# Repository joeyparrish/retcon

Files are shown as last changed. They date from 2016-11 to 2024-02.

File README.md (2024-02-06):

RetCon

# Retro Console Controller

Use comfortable wireless PS3 controllers on your old Sega or Nintendo system.

> :warning: **NOTE** :warning:: _**This project has been deprecated.**_
> 
> I bought receivers from 8bitdo that do much more than my homebrew project ever could, in a smaller space, for less money.
> For example, here you can get a Sega Genesis receiver for bluetooth controllers that is tiny and powered by the Sega itself: https://www.8bitdo.com/retro-receiver-genesis-mega-drive/
> 
> I had begun a redesign based on a microcontroller that I hoped would be powered by the console itself, and would use generic Bluetooth instead of PS3, but for $20 (as of Feb 2024) it's hard to beat what 8bitdo is doing.
> 
> Feel free to build off of this repo if you wish, but I'm abandoning it in favor of https://www.8bitdo.com/
> 
> -Joey

-----

The PS3 controllers pair with a Raspberry Pi, which translates the controller
inputs to the game console through an external circuit.

[The repository][] hosts the schematics, board layouts, and source code.

For a list of known issues, see our [issue tracker][].

[The repository]: https://github.com/cashpipeplusplus/retcon
[issue tracker]: https://github.com/cashpipeplusplus/retcon/issues

## Software

RetCon consists of three pieces of software that run on a Raspberry Pi:

 * retcon - reads events from the gamepad and toggle GPIO pins
 * trusting-steed - waits for gamepads and marks them as "trusted"
 * sixpair - waits for PS3 controllers over USB and pairs them for bluetooth

These run on the Raspberry Pi, and I do not recommend cross-compiling them.
To build them, check out the source on Raspbian, install the deps, then build
the debian package:

```sh
git clone https://github.com/cashpipeplusplus/retcon
sudo apt-get install libusb-dev pigpio python-gobject python-dbus
cd retcon/src/
fakeroot ./debian/rules binary
```

To install on Raspbian:

```sh
sudo dpkg -i ../retcon_0.0.1-1_armhf.deb
```

## Raspberry Pi SD card image

The SD card image is generated using a fork of a tool called pi-gen, which is
included as a submodule.

From retcon, you can check out the pi-gen code like this:

```sh
git submodule update --init --recursive
```

To build the SD image, first you must build the retcon debian package from
Raspbian.  Then, copy the deb file to your Linux machine and build the SD image
there.  Assuming the deb file is in the retcon folder, run this:

```sh
cd pi-gen
sudo ./build.sh ../retcon_0.0.1-1_armhf.deb
```

The output will appear in `deploy/`.

## Pre-built SD card image

Pre-built SD card images are available from the [releases][] page.

[releases]: https://github.com/cashpipeplusplus/retcon/releases

## Hardware

The Raspberry Pi communicates with the game console through an external
circuit.  Schematics and board layouts for this extra hardware can be found
in the `circuit/` folder.  The board file can be uploaded directly to
[DirtyPCBs][] if you want the boards printed for you.  More details can be
found in `circuit/README.md`.

[DirtyPCBs]: http://dirtypcbs.com/

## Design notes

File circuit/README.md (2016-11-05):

These are the schematic and board files for the external circuit part of the
project.  This circuit is driven by the Raspberry Pi and translates GPIO pins
to the game console.

These files were created with the free version of [Eagle][] v7.7.0.

 - sega.sch (Eagle Schematic)
 - sega.sch.1.png (screenshot of the schematic)
 - sega.sch.2.png (screenshot of the schematic)
 - sega.brd (Eagle Board)
 - sega.brd.png (screenshot of the board)

The board file can be uploaded directly to [DirtyPCBs][] to be printed.

[Eagle]: https://cadsoft.io/
[DirtyPCBs]: http://dirtypcbs.com/

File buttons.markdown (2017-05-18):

## Button Mappings

|PS3 |Master System |Genesis |NES |SNES |Output |
|---|---|---|---|---|---|
|D-pad |D-pad |D-pad |D-pad  |D-pad  |U, D, L, R|
|L stick |D-pad |D-pad |D-pad  |D-pad  |U, D, L, R|
|R stick |- |- |- |- |- |
|select |- |- |select |select |SL |
|start |- |start |start  |start  |ST |
|PS button |- |- |- |- |- |
|square |- |A |B |Y |A |
|X |button 1 |B |A |B |B |
|circle |button 2 |C |- |A |C |
|triangle  |- |- |- |X |X |
|L1 |- |- |- |TL |TL |
|R1 |- |- |- |TR |TR |
|L2 |- |- |- |- |- |
|R2 |- |C¹ |- |A |C¹ |
|L3 |- |- |- |- |- |
|R3 |- |- |- |- |- |

¹: Alternate binding for C on Genesis, for convenience

## Pin Mappings

|Output name |P1 connector pin² |P2 connector pin² |P1 BCM pin³ |P2 BCM pin³ |
|---|---|---|---|---|
|U | 8 |21 |14 | 9 |
|D |18 |11 |24 |17 |
|L |16 |13 |23 |27 |
|R |12 |15 |18 |22 |
|SL |38 |23 |20 |11 |
|ST |10 |19 |15 |10 |
|A |26 | 3 | 7 | 2 |
|B |24 | 5 | 8 | 3 |
|C |22 | 7 |25 | 4 |
|X |36 |27 |16 | 0 |
|TL |32 |29 |12 | 5 |
|TR |28 |31 | 1 | 6 |

²: Pins on the Raspberry Pi's GPIO connector

³: Pins on the Raspberry Pi's Broadcom CPU

See also: https://pinout.xyz/

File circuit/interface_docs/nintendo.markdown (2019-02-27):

# Nintendo Entertainment System and Super Nintendo Controller Interface

## Connectors

Sega made it so easy with DB9.  Nintendo's connectors are not only non-standard,
they changed the connector from the NES to the SNES.  The socket on the game
console is male, and the plug on the end of the controllers is female.

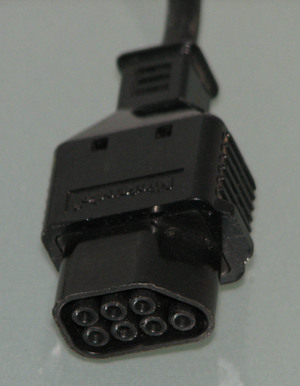
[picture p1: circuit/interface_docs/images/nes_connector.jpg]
female NES plug

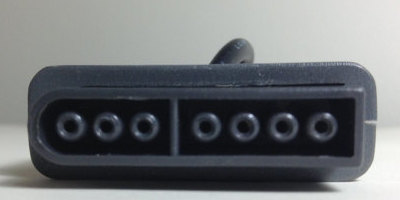
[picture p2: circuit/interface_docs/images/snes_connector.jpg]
female SNES plug


## Controller interfaces

The NES controller has a D-pad and buttons A, B, start, and select.
The SNES controller adds X, Y, and L & R shoulder buttons to the NES layout.
The controller interface is a 5V serial interface with active-low signals.
Pins are pulled high in the controller and pushing a button connects the pin
to ground.

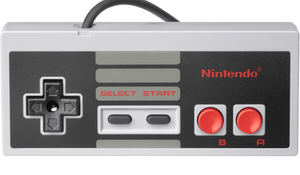
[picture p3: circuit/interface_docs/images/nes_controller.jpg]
NES controller

NES connector pins
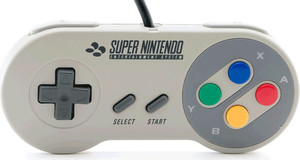
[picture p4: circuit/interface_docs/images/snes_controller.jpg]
SNES controller

SNES connector pins

The serial interface works by latching all of the button states into a shift
register, then clocking out each individual button state.  The button states
form an 8-bit (NES) or 16-bit (SNES) word.

|pin|signal |NES color¹|SNES color¹|
|---|---|---|---|
|1  |Ground (from console)|white |black |
|2  |(not used) | | |
|3  |(not used) | | |
|4  |Serial output |black |red |
|5  |Latch (from console) |green |yellow |
|6  |Clock (from console) |yellow |blue |
|7  |+5V (from console) |red |green |

¹: In the extension cords I bought... YMMV

|bit|NES button|SNES button|
|---|---|---|
|0  |A |B |
|1  |B |Y |
|2  |Select |Select |
|3  |Start |Start |
|4  |Up |Up |
|5  |Down |Down |
|6  |Left |Left |
|7  |Right |Right |
|8  |(not used)|A |
|9  |(not used)|X |
|10 |(not used)|L |
|11 |(not used)|R |
|12 |(not used)|(not used) |
|13 |(not used)|(not used) |
|14 |(not used)|(not used) |
|15 |(not used)|(not used) |

Any extra bits in the shift register's parallel input must be pulled high.

### External References

 - http://gamesx.com/wiki/doku.php?id=controls:nes_snes_controller
 - http://pinoutguide.com/Game/snescontroller_pinout.shtml

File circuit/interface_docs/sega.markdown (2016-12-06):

# Sega Genesis and Master System Controller Interface

## Connector

The connector is a slight variation on a normal DB9 connector.  The socket on
the game console is male, and the plug on the end of the controller is female.

A normal DB9 female plug won't fit into the Sega controller port.  The socket
on the game console is a little too deep, and the metal shielding on the female
plug makes the whole thing too wide.

It seems that the best way to connect our circuit to the Sega is via an
extension cable that is meant for Sega Genesis.

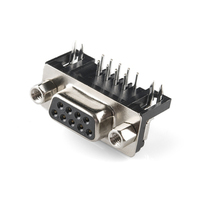
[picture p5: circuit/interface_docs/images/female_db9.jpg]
female DB9 plug

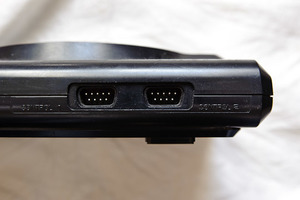
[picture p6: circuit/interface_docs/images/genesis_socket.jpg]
Sega Genesis controller socket

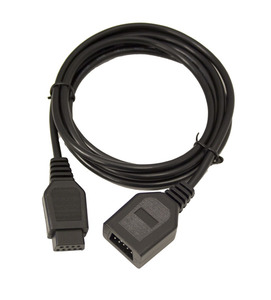
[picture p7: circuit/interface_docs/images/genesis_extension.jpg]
Sega Genesis extension cable


## Sega Master System Controller

The Master System controller has a D-pad and two buttons.  The controller
interface is a 5V parallel interface with active-low signals.  Pins are
pulled high in the controller and pushing a button connects the pin to ground.

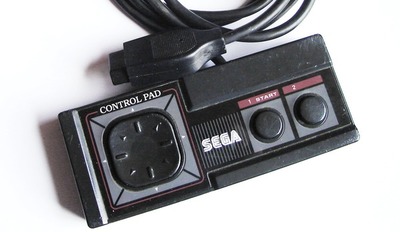
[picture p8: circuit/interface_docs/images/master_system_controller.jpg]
Sega Master System Controller

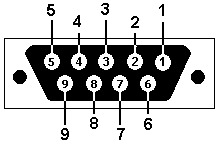
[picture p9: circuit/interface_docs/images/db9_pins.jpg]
DB9 connector pins


|pin|signal |
|---|---|
|1  |Up |
|2  |Down |
|3  |Left |
|4  |Right |
|5  |+5V (from console) |
|6  |Button 1 |
|7  |(not used) |
|8  |Ground (from console)|
|9  |Button 2 |

## Sega Genesis Controller

The Genesis controller has a D-pad, a start button, and buttons A, B, and C.
The controller interface is backward-compatible with the Sega Master System,
so a Genesis controller should work on a Master System.

To add more buttons while maintaining compatibility, the Sega Genesis adds a
select signal to the interface.  Based on the state of the select pin, the
controller multiplexes additional button states onto existing pins.  The select
pin is pulled high in the controller so that it is not left floating when the
controller is connected to a Master System.

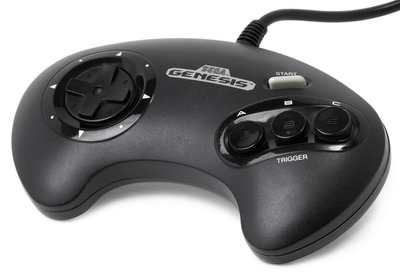
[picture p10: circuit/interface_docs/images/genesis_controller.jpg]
Sega Genesis Controller

DB9 connector pins

|pin|signal (select high) |signal (select low) |
|---|---|---|
|1  |Up |Up |
|2  |Down |Down |
|3  |Left |Ground |
|4  |Right |Ground |
|5  |+5V (from console) |+5V (from console) |
|6  |B Button |A Button |
|7  |Select (from console, +5V)|Select (from console, ground)|
|8  |Ground (from console) |Ground (from console) |
|9  |C Button |Start Button |

### External References

 - http://gamesx.com/wiki/doku.php?id=controls:megadrive_genesis_controller_3
 - http://www.haku.co.uk/pics/SegaJoypadPinout.jpg
 - https://www.cs.cmu.edu/~chuck/infopg/segasix.txt

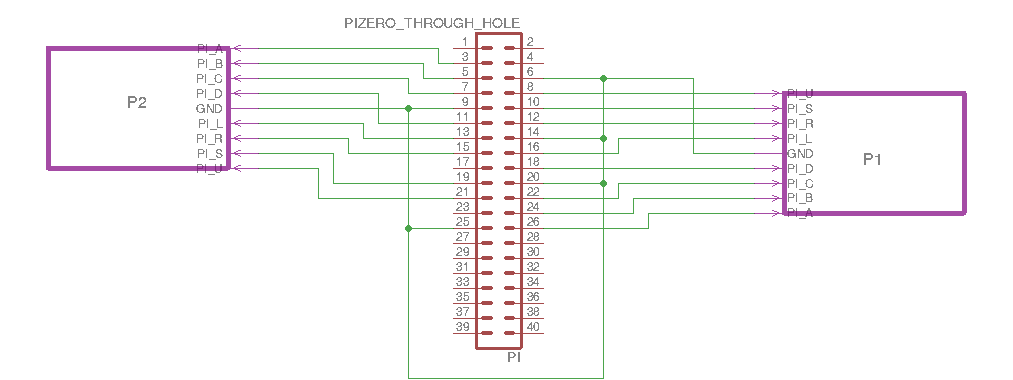
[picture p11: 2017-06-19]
circuit/sega.sch.2.png

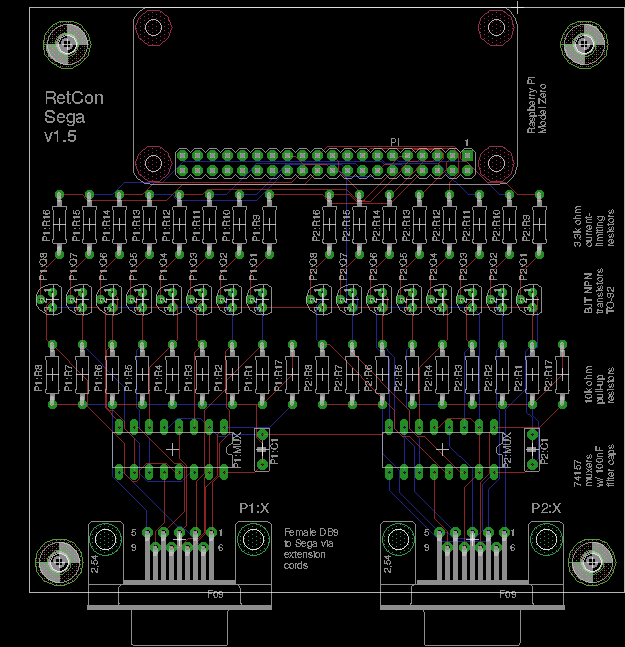
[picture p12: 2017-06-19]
circuit/sega.brd.png

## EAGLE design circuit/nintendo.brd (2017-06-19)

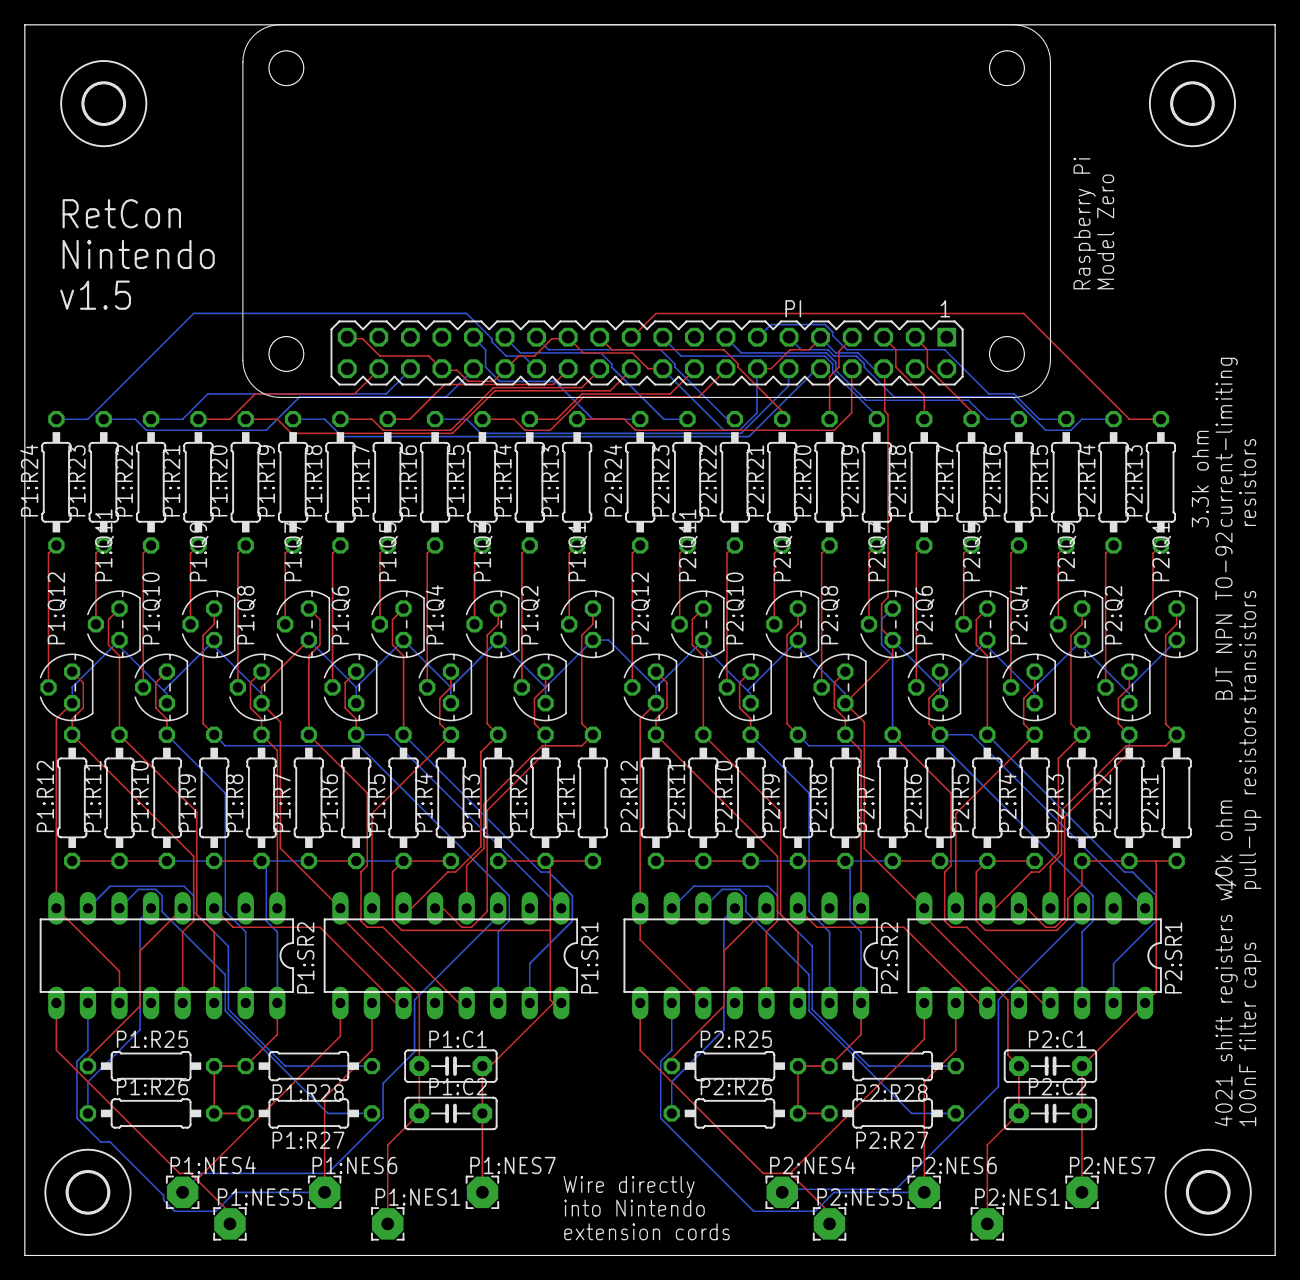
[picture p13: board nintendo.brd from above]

Board: 2 copper layers, 100.6 x 99.0 mm, 103 parts (0 on the bottom side), 91 nets.

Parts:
P1:C1, P1:C2, P2:C1, P2:C2: 100nF; C5B2.5
P1:NES1, P1:NES4, P1:NES5, P1:NES6, P1:NES7, P2:NES1, P2:NES4, P2:NES5, P2:NES6, P2:NES7: -; 2,54/1,0
P1:Q1, P1:Q2, P1:Q3, P1:Q4, P1:Q5, P1:Q6, P1:Q7, P1:Q8, P1:Q9, P1:Q10, P1:Q11, P1:Q12, P2:Q1, P2:Q2, P2:Q3, P2:Q4, P2:Q5, P2:Q6, P2:Q7, P2:Q8, P2:Q9, P2:Q10, P2:Q11, P2:Q12: 2N3904; TO92
P1:R1, P1:R2, P1:R3, P1:R4, P1:R5, P1:R6, P1:R7, P1:R8, P1:R9, P1:R10, P1:R11, P1:R12, P1:R25, P1:R26, P1:R27, P1:R28, P2:R1, P2:R2, P2:R3, P2:R4, P2:R5, P2:R6, P2:R7, P2:R8, P2:R9, P2:R10, P2:R11, P2:R12, P2:R25, P2:R26, P2:R27, P2:R28: 10k; 0207/10
P1:R13, P1:R14, P1:R15, P1:R16, P1:R17, P1:R18, P1:R19, P1:R20, P1:R21, P1:R22, P1:R23, P1:R24, P2:R13, P2:R14, P2:R15, P2:R16, P2:R17, P2:R18, P2:R19, P2:R20, P2:R21, P2:R22, P2:R23, P2:R24: 3.3k; 0207/10
P1:SR1, P1:SR2, P2:SR1, P2:SR2: 4021N; DIL16
PI: PIZERO_THROUGH_HOLE; PIZERO_THOUGH_HOLE
U$1, U$2, U$3, U$4: 3,2

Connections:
unnamed: P2:R14.2, PI.11
unnamed: P1:C1.1, P1:C2.1, P1:NES1.1, P1:Q1.3, P1:Q2.3, P1:Q3.3, P1:Q4.3, P1:Q5.3, P1:Q6.3, P1:Q7.3, P1:Q8.3, P1:Q9.3, P1:Q10.3, P1:Q11.3, P1:Q12.3, P1:SR1.8, P1:SR2.8, P1:SR2.11, P2:C1.1, P2:C2.1, P2:NES1.1, P2:Q1.3, P2:Q2.3, P2:Q3.3, P2:Q4.3, P2:Q5.3, P2:Q6.3, P2:Q7.3, P2:Q8.3, P2:Q9.3, P2:Q10.3, P2:Q11.3, P2:Q12.3, P2:SR1.8, P2:SR2.8, P2:SR2.11, PI.6, PI.9, PI.14, PI.20, PI.25, PI.30, PI.34, PI.39
unnamed: P2:R15.2, PI.13
unnamed: P2:R17.2, PI.3
unnamed: P2:R18.2, PI.5
unnamed: P2:R20.2, PI.7
unnamed: P2:R16.2, PI.15
unnamed: P2:R19.2, PI.19
unnamed: P2:R13.2, PI.21
unnamed: P1:R13.2, PI.8
unnamed: P1:R19.2, PI.10
unnamed: P1:R16.2, PI.12
unnamed: P1:R15.2, PI.16
unnamed: P1:R14.2, PI.18
unnamed: P1:R20.2, PI.22
unnamed: P1:R18.2, PI.24
unnamed: P1:R17.2, PI.26
unnamed: P2:R21.2, PI.23
unnamed: P2:R22.2, PI.27
unnamed: P2:R23.2, PI.29
unnamed: P2:R24.2, PI.31
unnamed: P1:R21.2, PI.38
unnamed: P1:R22.2, PI.36
unnamed: P1:R23.2, PI.32
unnamed: P1:R24.2, PI.28
P1:A: P1:Q5.1, P1:R5.2, P1:SR1.15
P1:B: P1:Q6.1, P1:R6.2, P1:SR1.1
P1:C: P1:Q8.1, P1:R8.2, P1:SR2.1
P1:CLK: P1:NES6.1, P1:SR1.10, P1:SR2.10
P1:D: P1:Q2.1, P1:R2.2, P1:SR1.5
P1:L: P1:Q3.1, P1:R3.2, P1:SR1.6
P1:LATCH: P1:NES5.1, P1:SR1.9, P1:SR2.9
P1:N$1: P1:Q9.2, P1:R21.1
P1:N$2: P1:Q1.2, P1:R13.1
P1:N$3: P1:Q10.2, P1:R22.1
P1:N$4: P1:Q11.2, P1:R23.1
P1:N$5: P1:Q12.2, P1:R24.1
P1:N$9: P1:Q2.2, P1:R14.1
P1:N$10: P1:Q3.2, P1:R15.1
P1:N$11: P1:Q4.2, P1:R16.1
P1:N$12: P1:Q5.2, P1:R17.1
P1:N$13: P1:Q6.2, P1:R18.1
P1:N$14: P1:Q7.2, P1:R19.1
P1:N$15: P1:Q8.2, P1:R20.1
P1:N$19: P1:SR1.11, P1:SR2.3
P1:N$20: P1:R25.1, P1:SR2.4
P1:N$21: P1:R26.1, P1:SR2.5
P1:N$22: P1:R27.1, P1:SR2.6
P1:N$23: P1:R28.1, P1:SR2.7
P1:OUT: P1:NES4.1, P1:SR1.3
P1:R: P1:Q4.1, P1:R4.2, P1:SR1.7
P1:SL: P1:Q9.1, P1:R9.2, P1:SR1.14
P1:ST: P1:Q7.1, P1:R7.2, P1:SR1.13
P1:TL: P1:Q11.1, P1:R11.2, P1:SR2.14
P1:TR: P1:Q12.1, P1:R12.2, P1:SR2.13
P1:U: P1:Q1.1, P1:R1.2, P1:SR1.4
P1:VCC: P1:C1.2, P1:C2.2, P1:NES7.1, P1:R1.1, P1:R2.1, P1:R3.1, P1:R4.1, P1:R5.1, P1:R6.1, P1:R7.1, P1:R8.1, P1:R9.1, P1:R10.1, P1:R11.1, P1:R12.1, P1:R25.2, P1:R26.2, P1:R27.2, P1:R28.2, P1:SR1.16, P1:SR2.16
P1:X: P1:Q10.1, P1:R10.2, P1:SR2.15
P2:A: P2:Q5.1, P2:R5.2, P2:SR1.15
P2:B: P2:Q6.1, P2:R6.2, P2:SR1.1
P2:C: P2:Q8.1, P2:R8.2, P2:SR2.1
P2:CLK: P2:NES6.1, P2:SR1.10, P2:SR2.10
P2:D: P2:Q2.1, P2:R2.2, P2:SR1.5
P2:L: P2:Q3.1, P2:R3.2, P2:SR1.6
P2:LATCH: P2:NES5.1, P2:SR1.9, P2:SR2.9
P2:N$1: P2:Q9.2, P2:R21.1
P2:N$2: P2:Q1.2, P2:R13.1
P2:N$3: P2:Q10.2, P2:R22.1
P2:N$4: P2:Q11.2, P2:R23.1
P2:N$5: P2:Q12.2, P2:R24.1
P2:N$9: P2:Q2.2, P2:R14.1
P2:N$10: P2:Q3.2, P2:R15.1
P2:N$11: P2:Q4.2, P2:R16.1
P2:N$12: P2:Q5.2, P2:R17.1
P2:N$13: P2:Q6.2, P2:R18.1
P2:N$14: P2:Q7.2, P2:R19.1
P2:N$15: P2:Q8.2, P2:R20.1
P2:N$19: P2:SR1.11, P2:SR2.3
P2:N$20: P2:R25.1, P2:SR2.4
P2:N$21: P2:R26.1, P2:SR2.5
P2:N$22: P2:R27.1, P2:SR2.6
P2:N$23: P2:R28.1, P2:SR2.7
P2:OUT: P2:NES4.1, P2:SR1.3
P2:R: P2:Q4.1, P2:R4.2, P2:SR1.7
P2:SL: P2:Q9.1, P2:R9.2, P2:SR1.14
P2:ST: P2:Q7.1, P2:R7.2, P2:SR1.13
P2:TL: P2:Q11.1, P2:R11.2, P2:SR2.14
P2:TR: P2:Q12.1, P2:R12.2, P2:SR2.13
P2:U: P2:Q1.1, P2:R1.2, P2:SR1.4
P2:VCC: P2:C1.2, P2:C2.2, P2:NES7.1, P2:R1.1, P2:R2.1, P2:R3.1, P2:R4.1, P2:R5.1, P2:R6.1, P2:R7.1, P2:R8.1, P2:R9.1, P2:R10.1, P2:R11.1, P2:R12.1, P2:R25.2, P2:R26.2, P2:R27.2, P2:R28.2, P2:SR1.16, P2:SR2.16
P2:X: P2:Q10.1, P2:R10.2, P2:SR2.15

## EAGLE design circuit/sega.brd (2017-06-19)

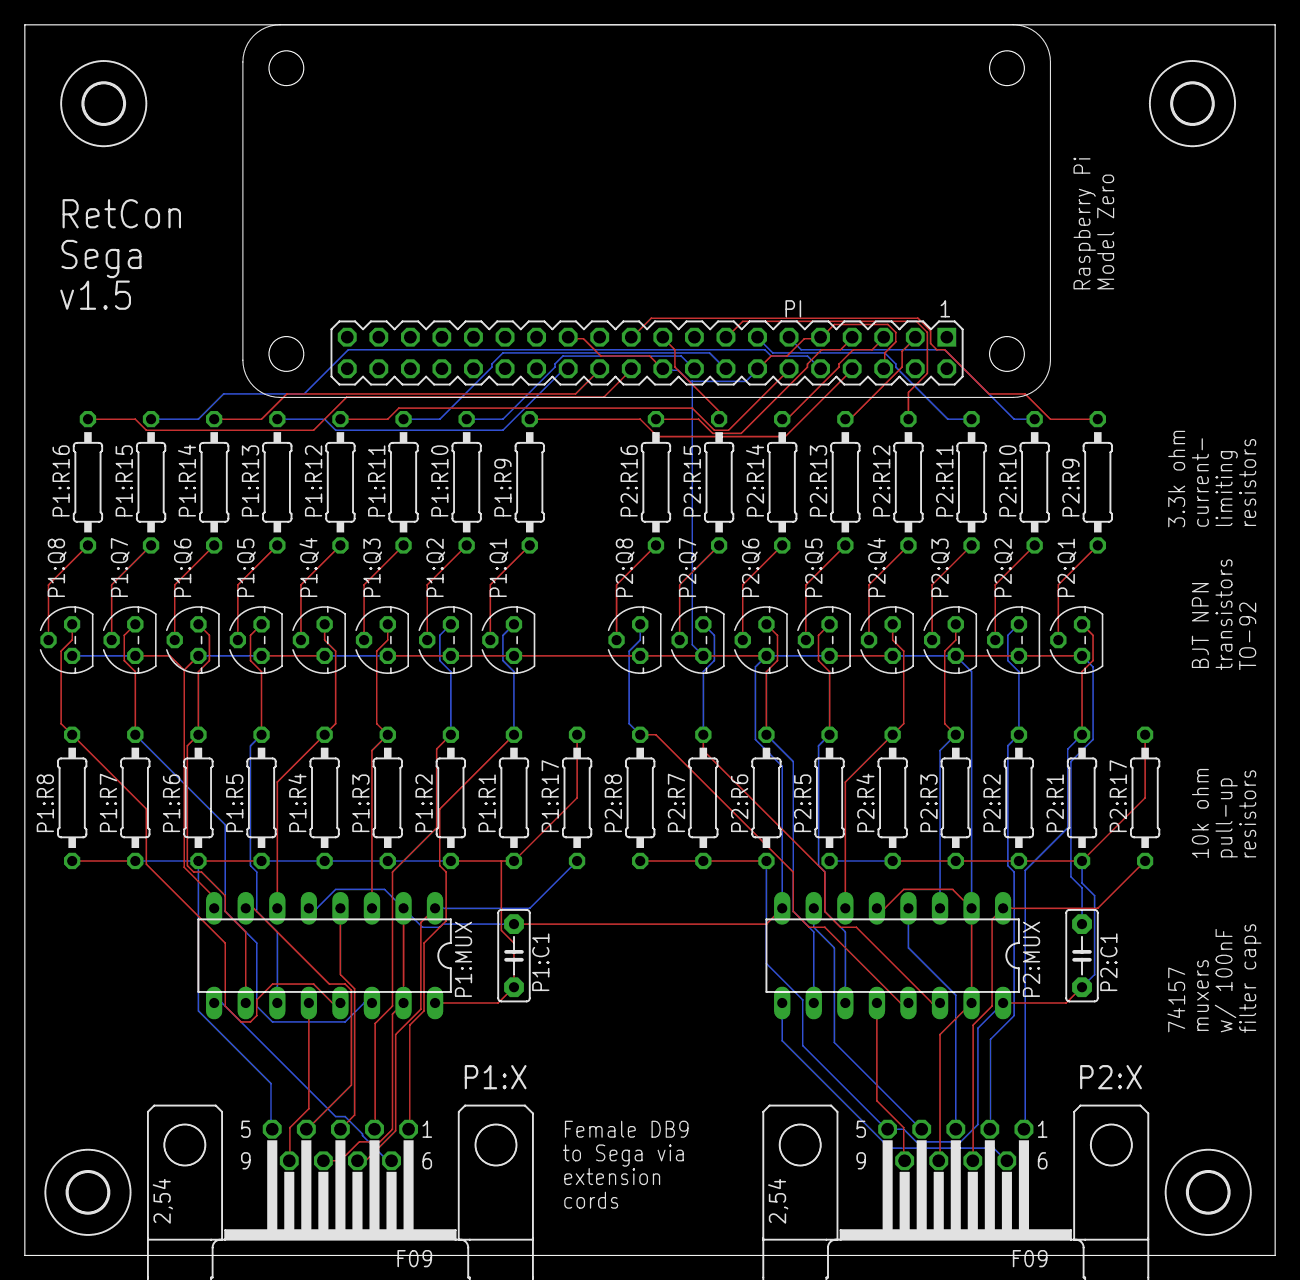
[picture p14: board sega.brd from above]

Board: 2 copper layers, 100.6 x 99.0 mm, 61 parts (0 on the bottom side), 61 nets.

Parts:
P1:C1, P2:C1: 100nF; C5B2.5
P1:MUX, P2:MUX: 74LS157N; DIL16
P1:Q1, P1:Q2, P1:Q3, P1:Q4, P1:Q5, P1:Q6, P1:Q7, P1:Q8, P2:Q1, P2:Q2, P2:Q3, P2:Q4, P2:Q5, P2:Q6, P2:Q7, P2:Q8: 2N3904; TO92
P1:R1, P1:R2, P1:R3, P1:R4, P1:R5, P1:R6, P1:R7, P1:R8, P1:R17, P2:R1, P2:R2, P2:R3, P2:R4, P2:R5, P2:R6, P2:R7, P2:R8, P2:R17: 10k; 0207/10
P1:R9, P1:R10, P1:R11, P1:R12, P1:R13, P1:R14, P1:R15, P1:R16, P2:R9, P2:R10, P2:R11, P2:R12, P2:R13, P2:R14, P2:R15, P2:R16: 3.3k; 0207/10
P1:X, P2:X: -; F09H
PI: PIZERO_THROUGH_HOLE; PIZERO_THOUGH_HOLE
U$1, U$2, U$3, U$4: 3,2

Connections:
GND: P1:C1.1, P1:MUX.2, P1:MUX.5, P1:MUX.8, P1:MUX.15, P1:Q1.3, P1:Q2.3, P1:Q3.3, P1:Q4.3, P1:Q5.3, P1:Q6.3, P1:Q7.3, P1:Q8.3, P1:X.8, P2:C1.1, P2:MUX.2, P2:MUX.5, P2:MUX.8, P2:MUX.15, P2:Q1.3, P2:Q2.3, P2:Q3.3, P2:Q4.3, P2:Q5.3, P2:Q6.3, P2:Q7.3, P2:Q8.3, P2:X.8, PI.6, PI.9, PI.14, PI.20, PI.25
unnamed: P2:R10.2, PI.11
unnamed: P2:R11.2, PI.13
unnamed: P2:R13.2, PI.3
unnamed: P2:R14.2, PI.5
unnamed: P2:R16.2, PI.7
unnamed: P2:R12.2, PI.15
unnamed: P2:R15.2, PI.19
unnamed: P2:R9.2, PI.21
unnamed: P1:R9.2, PI.8
unnamed: P1:R15.2, PI.10
unnamed: P1:R12.2, PI.12
unnamed: P1:R11.2, PI.16
unnamed: P1:R10.2, PI.18
unnamed: P1:R16.2, PI.22
unnamed: P1:R14.2, PI.24
unnamed: P1:R13.2, PI.26
P1:A: P1:MUX.11, P1:Q5.1, P1:R5.2
P1:A|B: P1:MUX.9, P1:X.6
P1:B: P1:MUX.10, P1:Q6.1, P1:R6.2
P1:C: P1:MUX.13, P1:Q8.1, P1:R8.2
P1:D: P1:Q2.1, P1:R2.2, P1:X.2
P1:G|L: P1:MUX.4, P1:X.3
P1:G|R: P1:MUX.7, P1:X.4
P1:L: P1:MUX.3, P1:Q3.1, P1:R3.2
P1:N$2: P1:Q1.2, P1:R9.1
P1:N$9: P1:Q2.2, P1:R10.1
P1:N$10: P1:Q3.2, P1:R11.1
P1:N$11: P1:Q4.2, P1:R12.1
P1:N$12: P1:Q5.2, P1:R13.1
P1:N$13: P1:Q6.2, P1:R14.1
P1:N$14: P1:Q7.2, P1:R15.1
P1:N$15: P1:Q8.2, P1:R16.1
P1:R: P1:MUX.6, P1:Q4.1, P1:R4.2
P1:S: P1:MUX.14, P1:Q7.1, P1:R7.2
P1:SEL: P1:MUX.1, P1:R17.1, P1:X.7
P1:S|C: P1:MUX.12, P1:X.9
P1:U: P1:Q1.1, P1:R1.2, P1:X.1
P1:VCC: P1:C1.2, P1:MUX.16, P1:R1.1, P1:R2.1, P1:R3.1, P1:R4.1, P1:R5.1, P1:R6.1, P1:R7.1, P1:R8.1, P1:R17.2, P1:X.5
P2:A: P2:MUX.11, P2:Q5.1, P2:R5.2
P2:A|B: P2:MUX.9, P2:X.6
P2:B: P2:MUX.10, P2:Q6.1, P2:R6.2
P2:C: P2:MUX.13, P2:Q8.1, P2:R8.2
P2:D: P2:Q2.1, P2:R2.2, P2:X.2
P2:G|L: P2:MUX.4, P2:X.3
P2:G|R: P2:MUX.7, P2:X.4
P2:L: P2:MUX.3, P2:Q3.1, P2:R3.2
P2:N$2: P2:Q1.2, P2:R9.1
P2:N$9: P2:Q2.2, P2:R10.1
P2:N$10: P2:Q3.2, P2:R11.1
P2:N$11: P2:Q4.2, P2:R12.1
P2:N$12: P2:Q5.2, P2:R13.1
P2:N$13: P2:Q6.2, P2:R14.1
P2:N$14: P2:Q7.2, P2:R15.1
P2:N$15: P2:Q8.2, P2:R16.1
P2:R: P2:MUX.6, P2:Q4.1, P2:R4.2
P2:S: P2:MUX.14, P2:Q7.1, P2:R7.2
P2:SEL: P2:MUX.1, P2:R17.1, P2:X.7
P2:S|C: P2:MUX.12, P2:X.9
P2:U: P2:Q1.1, P2:R1.2, P2:X.1
P2:VCC: P2:C1.2, P2:MUX.16, P2:R1.1, P2:R2.1, P2:R3.1, P2:R4.1, P2:R5.1, P2:R6.1, P2:R7.1, P2:R8.1, P2:R17.2, P2:X.5

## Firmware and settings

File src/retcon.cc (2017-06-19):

/*
 * This file is part of RetCon: Retro Console Controller.
 *
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
 * You should have received a copy of the GNU General Public License
 * along with RetCon.  If not, see <http://www.gnu.org/licenses/>.
 */

// This application runs on a Raspberry Pi.  It reads from a paired PS3
// controller and writes to the GPIO pins.  The GPIO pins drive an external
// circuit which interfaces to the game console.

#include <errno.h>
#include <fcntl.h>
#include <linux/joystick.h>
#include <pigpio.h>
#include <signal.h>
#include <stdint.h>
#include <stdio.h>
#include <stdlib.h>
#include <string.h>
#include <sys/select.h>
#include <sys/stat.h>
#include <sys/types.h>
#include <termios.h>
#include <unistd.h>

#include <map>
#include <vector>

// pigpio installs signal handlers that shut down the application on a large
// number of signals.  These are signals that are harmless and are used to
// suspend and background applications.  For each of these, we will override
// the pigpio handler so that these signals can be used normally.
const std::vector<int> harmless_signals = {
  SIGCONT, SIGTSTP, SIGTTIN, SIGTTOU
};

// Output represents the application's output to the external circuit through
// the Raspberry Pi's GPIO pins.
class Output {
 public:
  // These represent GPIO outputs which map to both Sega and Nintendo buttons.
  // See buttons.markdown for details.
  typedef enum {
    UP,
    DOWN,
    LEFT,
    RIGHT,
    SELECT,
    START,
    A,  // A on Sega Genesis, Y on SNES, B on NES
    B,  // B on Sega Genesis, B on SNES, A on NES, 1 on Sega Master System
    C,  // C on Sega Genesis, A on SNES, 2 on Sega Master System
    X,  // X on SNES
    TOP_LEFT,
    TOP_RIGHT,
  } Button;

  // Player 1, player 2
  typedef enum {
    P1 = 1,
    P2 = 2,
  } Player;

  static void init() { instance_ = new Output(); }
  static inline Output* instance() { return instance_; }

  // Update the relevant GPIO pin state.
  inline void write(Player player, Button b, bool on) {
    if (on) fprintf(stderr, "P%d button %d\n", player, b);
    gpioWrite(pin_maps_[player].at(b), on);
  }

 private:
  Output();

  static Output* instance_;

  // Maps buttons for each player to specific GPIO pins.
  const std::map<Button, int> pin_maps_[3];
};

// static
Output* Output::instance_ = NULL;

Output::Output()
    : pin_maps_({
      // slot zero is unused, so that the P1 and P2 enums have more natural
      // values.
      {},

      {  // P1
        { UP, 14 },
        { DOWN, 24 },
        { LEFT, 23 },
        { RIGHT, 18 },
        { SELECT, 20 },
        { START, 15 },
        { A, 7 },
        { B, 8 },
        { C, 25 },
        { X, 16 },
        { TOP_LEFT, 12 },
        { TOP_RIGHT, 1 },
      },
      {  // P2
        { UP, 9 },
        { DOWN, 17 },
        { LEFT, 27 },
        { RIGHT, 22 },
        { SELECT, 11 },
        { START, 10 },
        { A, 2 },
        { B, 3 },
        { C, 4 },
        { X, 0 },
        { TOP_LEFT, 5 },
        { TOP_RIGHT, 6 },
      },
    }) {
  // Init GPIO.
  if (gpioInitialise() == PI_INIT_FAILED) {
    fprintf(stderr, "GPIO init failed.\n");
    exit(1);
  }

  // Ignore harmless signals, on which pigpio would otherwise exit.
  for (auto& sig : harmless_signals) {
    struct sigaction action;
    memset(&action, 0, sizeof(action));
    action.sa_handler = SIG_DFL;
    if (sigaction(sig, &action, NULL) != 0) {
      fprintf(stderr, "Signal handler %d could not be installed.\n", sig);
      exit(1);
    }
  }

  // Configure the output pins and clear them.
  for (auto& map : pin_maps_) {
    for (auto& kv : map) {
      gpioSetMode(kv.second, PI_OUTPUT);
      gpioWrite(kv.second, 0);
    }
  }
}

// Input is an abstract base which represents input methods.
class Input {
 public:
  Input(int fd);
  virtual ~Input() {}

  // Polls all inputs.  Never returns.
  static void poll();

 protected:
  // Connect to the input, if not already connected.
  virtual bool connect() = 0;

  // Read button presses from the input.
  virtual bool read() = 0;

  // Make fd_ non-blocking.
  void make_fd_nonblocking();

  // A file descriptor representing the input.
  int fd_;

  // A vector of all existing input objects.
  static std::vector<Input*> inputs_;
};

// static
std::vector<Input*> Input::inputs_;

Input::Input(int fd) : fd_(fd) {
  // Register this input instance with the static list.
  inputs_.push_back(this);
}

void Input::make_fd_nonblocking() {
  int flags = fcntl(fd_, F_GETFL, 0);
  fcntl(fd_, F_SETFL, flags | O_NONBLOCK);
}

// static
void Input::poll() {
  while (true) {
    int max_fd = -1;
    int num_fds = 0;
    fd_set fds;
    FD_ZERO(&fds);

    // Collect a set of file descriptors representing all inputs.
    for (auto& input : inputs_) {
      input->connect();
      if (input->fd_ < 0) continue;  // No file descriptor at the moment.
      max_fd = std::max(max_fd, input->fd_);
      ++num_fds;
      FD_SET(input->fd_, &fds);
    }

    // Wait for up to 1 second for any of them to have data.
    struct timeval tv;
    tv.tv_sec = 1;
    tv.tv_usec = 0;
    int rv = select(max_fd + 1, &fds, NULL, NULL, &tv);
    //fprintf(stderr, "Waited for %d fds, %d are ready\n", num_fds, rv);

    // If there are any inputs with data, loop through them.
    if (rv > 0) {
      for (auto& input : inputs_) {
        if (input->fd_ < 0) continue;  // No file descriptor at the moment.
        if (FD_ISSET(input->fd_, &fds)) {
          // Read all the data available in each input.
          while (input->read()) {}
        }
      }
    }
  }
}

// Input from a PS3 controller.
class PS3 : public Input {
 public:
  PS3(Output::Player player, const char* path);
  virtual ~PS3() {}

 protected:
  virtual bool connect() override final;
  virtual bool read() override final;

 private:
  // The PS3 buttons.  The enum value is the corresponding event number.
  typedef enum {
    SELECT = 0,
    L3,
    R3,
    START,
    UP,
    RIGHT,
    DOWN,
    LEFT,
    L2,
    R2,
    L1,
    R1,
    TRIANGLE,
    CIRCLE,
    X,
    SQUARE,
    PS,
  } Button;

  // The PS3 analog sticks.  The enum value is the corresponding stick number.
  typedef enum {
    LEFT_ANALOG = 0,
    RIGHT_ANALOG,
  } Stick;

  // Which player this input is tied to.
  const Output::Player player_;

  // The path to the input device.
  const char* path_;

  // A map from event numbers to output buttons.
  const std::map<int, Output::Button> button_map_;

  // A pair of output buttons, representing the outputs to use for the negative
  // and positive ends of one analog axis.
  typedef std::pair<Output::Button, Output::Button> AxisOutputs;
  // A pair of AxisOutputs, representing the vertical and horizontal axes of
  // one analog stick.
  typedef std::pair<AxisOutputs, AxisOutputs> StickOutputs;
  // A map from analog stick numbers to output buttons.
  const std::map<int, StickOutputs> stick_map_;
};

PS3::PS3(Output::Player player, const char* path)
    : Input(-1),
      player_(player),
      path_(path),
      // Not every PS3 button has a mapping here.
      button_map_({
        { UP, Output::UP },
        { RIGHT, Output::RIGHT },
        { DOWN, Output::DOWN },
        { LEFT, Output::LEFT },
        { SELECT, Output::SELECT },
        { START, Output::START },
        { SQUARE, Output::A },
        { X, Output::B },
        { CIRCLE, Output::C },
        { TRIANGLE, Output::X },
        { L1, Output::TOP_LEFT },
        { R1, Output::TOP_RIGHT },
        { R2, Output::C },  // Alternate C
      }),
      stick_map_({
        { LEFT_ANALOG, {  // Alternate D-pad
          {Output::UP, Output::DOWN},
          {Output::LEFT, Output::RIGHT},
        } },
      }) {}

bool PS3::connect() {
  if (fd_ >= 0) {
    // already connected.
    return true;
  }

  // try to connect
  fd_ = open(path_, O_RDONLY);
  if (fd_ < 0) {
    // failed to connect
    return false;
  }

  // connected
  fprintf(stderr, "Connected: %s\n", path_);
  make_fd_nonblocking();
  return true;
}

bool PS3::read() {
  js_event event;
  int bytes = ::read(fd_, &event, sizeof(event));
  if (bytes != sizeof(event)) {
    if (errno != EAGAIN) {
      fprintf(stderr, "Failed to read: %s\n", path_);
      // Disconnect.
      close(fd_);
      fd_ = -1;
    }
    return false;
  }

  Output* output = Output::instance();

  // Handle button events.
  if (event.type & JS_EVENT_BUTTON) {
#ifdef DEBUG
    fprintf(stderr, "number: 0x%02x, value: 0x%04x\n",
            event.number, event.value);
#endif
    // If this button is mapped, write to the output.
    auto it = button_map_.find(event.number);
    if (it != button_map_.end()) {
      output->write(player_, it->second, event.value);
    }
  }

  // Handle axis events.
  if (event.type & JS_EVENT_AXIS) {
#ifdef DEBUG
    fprintf(stderr, "number: 0x%02x, value: %d\n",
            event.number, event.value);
#endif
    // If this stick is mapped, interpret the analog value.
    int stick_number = event.number >> 1;
    int axis_number = event.number & 1;
    auto it = stick_map_.find(stick_number);
    if (it != stick_map_.end()) {
      // Decide which axis it is.
      auto stick_outputs = it->second;
      auto axis_outputs =
          axis_number ? stick_outputs.first : stick_outputs.second;

      if (event.value < -20000) {
        // For large negative values, output true to the negative output,
        // false to the positive output.
        output->write(player_, axis_outputs.first, true);
        output->write(player_, axis_outputs.second, false);
      } else if (event.value > 20000) {
        // For large positive values, output false to the negative output,
        // true to the positive output.
        output->write(player_, axis_outputs.first, false);
        output->write(player_, axis_outputs.second, true);
      } else {
        // For values that are in the middle, output false to both outputs.
        output->write(player_, axis_outputs.first, false);
        output->write(player_, axis_outputs.second, false);
      }
    }
  }

  return true;
}

// Input from the keyboard (stdin).
// Used for testing without bluetooth.
class Keyboard : public Input {
 public:
  Keyboard();
  virtual ~Keyboard() {}

 protected:
  virtual bool connect() override final;
  virtual bool read() override final;

 private:
  // Restore normal terminal echo settings.
  static void restore_echo();

  // Disable echo of input on the terminal.
  static void disable_echo();

  // The original terminal flags, saved by disable_echo(),
  // restored by restore_echo().
  static int orig_lflag_;

  // A map of characters to output buttons.
  const std::map<int, Output::Button> button_map_;
};

// static
int Keyboard::orig_lflag_;

Keyboard::Keyboard()
    : Input(STDIN_FILENO),  // Always read from stdin
      button_map_({
        { 'u', Output::UP },
        { 'd', Output::DOWN },
        { 'l', Output::LEFT },
        { 'r', Output::RIGHT },
        { 'e', Output::SELECT },
        { 's', Output::START },
        { 'a', Output::A },
        { 'b', Output::B },
        { 'c', Output::C },
        { 'x', Output::X },
        { '<', Output::TOP_LEFT },
        { '>', Output::TOP_RIGHT },
      }) {
  // Make stdin non-blocking.
  make_fd_nonblocking();
  // Disable echo of input on the terminal.
  disable_echo();
  // At exit, restore terminal settings.
  atexit(restore_echo);
}

bool Keyboard::connect() {
  // Always connected.
  return true;
}

bool Keyboard::read() {
  // Read one character.
  char c;
  int bytes = ::read(STDIN_FILENO, &c, 1);
  if (bytes != 1) {
    return false;
  }

  // Convert the character to lowercase, for use in the button map.
  char lower_c = c | 0x20;
  // If the original character was lowercase, we output to P1, otherwise P2.
  bool is_lower = lower_c == c;
  Output::Player player = is_lower ? Output::P1 : Output::P2;
  Output* output = Output::instance();

  // If the character is in the map,
  // press the corresponding output button briefly.
  auto it = button_map_.find(lower_c);
  if (it != button_map_.end()) {
#ifdef DEBUG
    fprintf(stderr, "'%c'\n", c);
#endif
    output->write(player, it->second, 1);
    usleep(100 * 1000);  // 0.1 seconds
    output->write(player, it->second, 0);
  }
  return true;
}

// static
void Keyboard::restore_echo() {
  fprintf(stderr, "Restoring echo.\n");
  struct termios t;
  tcgetattr(STDIN_FILENO, &t);
  t.c_lflag = orig_lflag_;
  tcsetattr(STDIN_FILENO, TCSANOW, &t);
}

// static
void Keyboard::disable_echo() {
  fprintf(stderr, "Disabling echo.\n");
  struct termios t;
  tcgetattr(STDIN_FILENO, &t);
  orig_lflag_ = t.c_lflag;
  t.c_lflag &= ~(ICANON|ECHO);
  tcsetattr(STDIN_FILENO, TCSANOW, &t);
}

int main() {
  // Initialize output.
  Output::init();
  // Listen on stdin, for debugging.
  Keyboard keyboard;
  // Listen for PS3 controllers for both P1 and P2.
  PS3 ps3_p1(Output::P1, "/dev/input/js0");
  PS3 ps3_p2(Output::P2, "/dev/input/js1");
  // Read input forever.  Never returns.
  Input::poll();
  return 0;
}

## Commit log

2016-11-04 Add schematic and board for circuit v1.1
    Closes #6
    [sega.brd, sega.sch]
2016-11-04 Update circuit design to v1.2
    - Raspberry Pi Zero mounted directly to the board replaces header
    - DB9 connectors replace individual jumper wires to the controller
    [sega.brd, sega.sch]
2016-11-05 Add missing pull-up resistor to circuit
    A pull-up was missing on the select pin.
    [sega.brd, sega.sch]
2016-11-05 Hide value layer and add more pngs
    This layer is ignored by DirtyPCBs, so the board in Eagle is now more
    representative of the final hardware. Also adds PNGs of the board and
    every part of the schematic.
    [sega.brd]
2016-11-15 Add explicit junctions to the schematic
    [sega.sch]
2016-12-06 Fix swapped pins in sega interface docs
    Pin 5 is VCC, pin 7 is select. Whoops.
2017-05-05 Fix Sega DB9 placement
    These connectors were too far from the edge of the board, and it made
    it very difficult to connect the extension cord. I had to modify the
    cord to get v1.2 working. This fixes the placement and updates the
    version number to v1.3.
    [sega.brd]
2017-05-05 Replace optocouplers with transistors
    This makes the board cheaper and frees up some space for additional
    hardware in future revisions. This is hardware v1.4.
    [sega.brd, sega.sch]
2017-05-18 Document button mappings
    This includes mappings for Nintendo systems, even though this has not
    been implemented yet.
2017-05-18 Fix button mapping doc
    I left out a cell in the table before.
    This also adds a footnote explaining why there is a duplicate row.
2017-05-18 Factor pin mappings out of button mapping table
2017-06-19 Fix Sega board, v1.5
    - Fix pin names and directions
    - Fix missing connections to GND
    - Add missing junctions to the schematic
    Closes #19
    [sega.brd, sega.sch]
2017-06-19 Add Nintendo circuit, v1.5
    Should work with either NES or SNES.
    Closes #7
    [nintendo.brd, nintendo.sch]
2017-06-19 Update button mappings to include Nintendo outputs
    Issue #7
    [retcon.cc]
2019-02-27 Add docs on wire colors in Nintendo extension cords

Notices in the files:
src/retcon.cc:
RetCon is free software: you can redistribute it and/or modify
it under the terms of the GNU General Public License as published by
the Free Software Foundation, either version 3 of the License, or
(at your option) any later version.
